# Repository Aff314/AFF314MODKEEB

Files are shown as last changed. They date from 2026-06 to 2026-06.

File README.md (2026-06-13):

# AFF314MODKEEB
AFF314MODKEEB is a 4x12 lowprofile keyboard. What makes it special are its modules. You can attach modules on top or on the right side which are connected with are then connected by magnets.

I had the idea because I daily drive 40% and 75% keyboards. I wanted to have one keyboard which can be used for both. With this keyboard you can have a full sized keyboard with number-keys, f-keys and arrow keys if you need it for a game or programm. But if you want to have a more minimal keyboard you can just detach the modules and have a nice and compact 40% keyboard. 

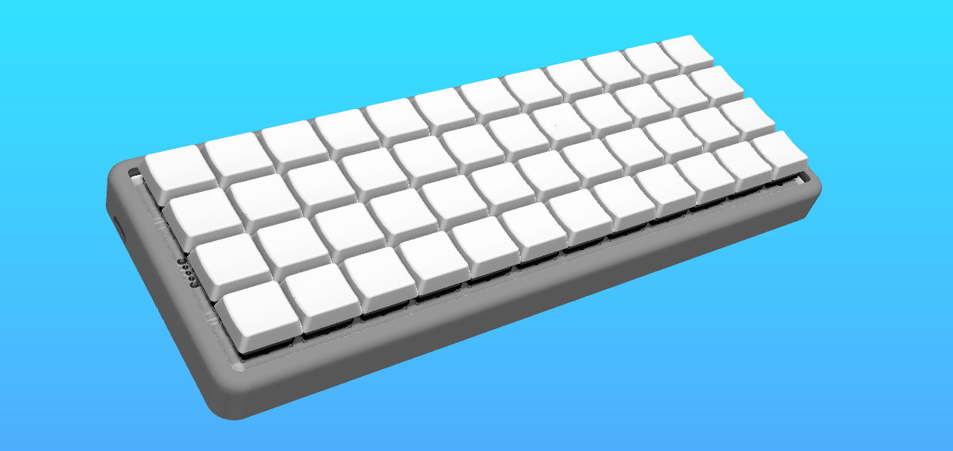
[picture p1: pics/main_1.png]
main_1


## Modules
You can attach the modules on top and on the right side.
So far I have designed three modules.

One for the right side. It has arrow-keys plus six extra keys that can be used for what ever you like.
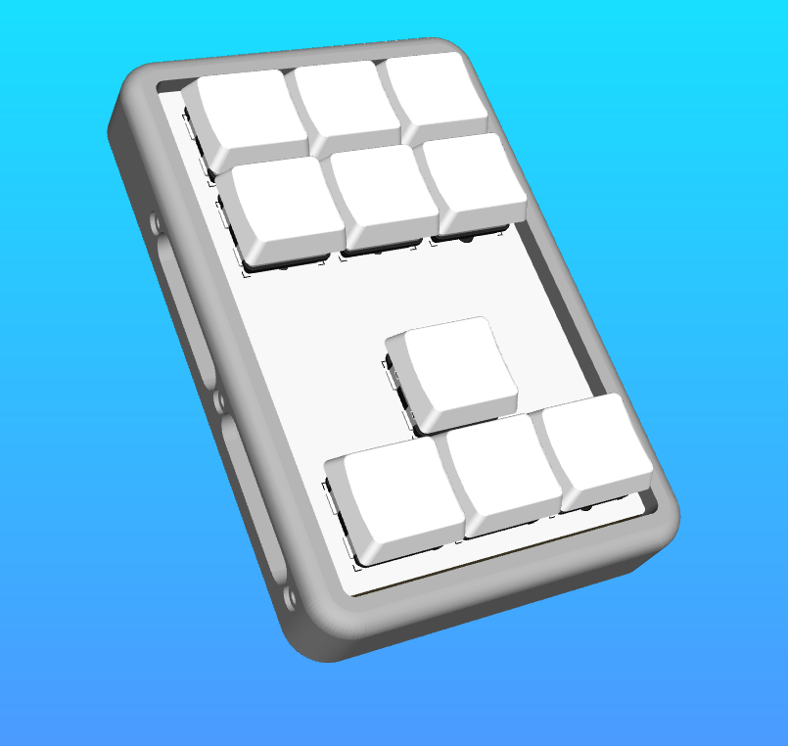
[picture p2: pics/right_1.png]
right_picture


The two that go on top are either a number or f-key row or a number plus f-key module. I decided to only order the pcbs for the number plus f-key module since you can type the numbers and f-keys also with layers so when I really need the f-keys or numbers the others don't hurt and it would take away from that convenience I wanted if you have so many modules laying around.
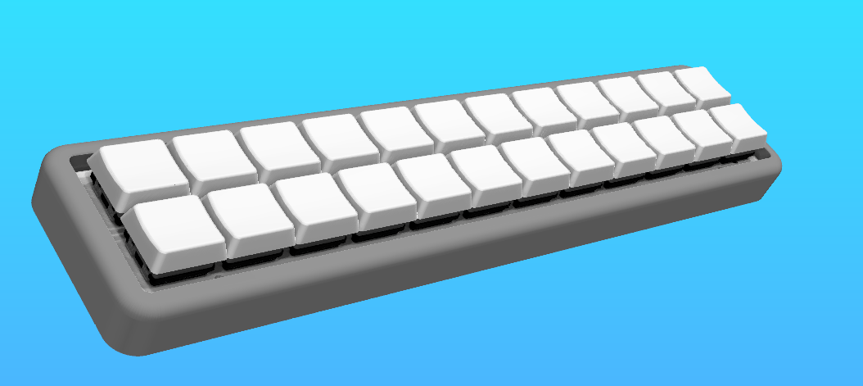
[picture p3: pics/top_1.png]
top_picture


If you want to you can design your own modules. You can use the same cases I designed and you have to modify the [pcbs](./pcb).

## Building
If you want to build the keyboard you have to not only solder on the pcb but also solder some wires. Once the keyboard is built I will add pictures for better understanding.

### Flashing
To flash the firmware you have to download the [UF2 file](./firmware/firmware.uf2).

### PCB
On the pcbs you first have to solder on all the diodes and hotswap sockets. Then you can solder on the power switch if you want to use one, because you can also use it without a powerswitch and solder the battery directly or just use it wired.

### Connectors
Before we wire everything we need the prepare the connectors. For this you need to print the [mounting bracktets](./3d). Then you can melt the heat inserts in the mounting bracket and attach it to the magnetic connector.

### Case
We also need to prepare the case. This is pretty straight forward as you only need to add the heat inserts.

### Wiring
We will start with the magnetic connectors we have prepared. We need to wire the cables to the pins. It is probably a good idea to use heat shrink tubing to isolate the exposed pins right by eachother but you dont have to. Once the wires are soldered to them we take them and mount them inside the case.
Look at the [schematics](./pics) and at the [wiring_guides](./pics) for help.

You can wire them to the mcu now. You also need to wire the rows and columns from the pcb to the mcu. For this you can take a look at the pcb but I will also add pictures once it's build.
At last you can wire the battery.

### MCU
The nice nano or if built wired the rp2040 will fit perfectly in the cutout for it in the bottom of the case. Optionaly you could glue it in place but it will also hold on its own so there is no need fo it unless you want the most secure fit.

## Fallout
I made this keyboard for fallout from hackclub and they give the chance for you to show off your project in a magazine. This is my page for zine. I will change it once I've built it irl because the real pictures would make it look way better.

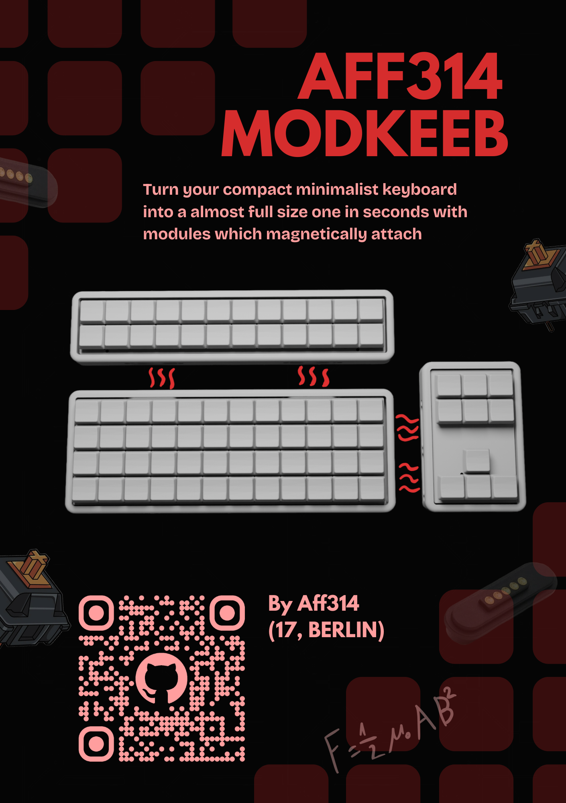
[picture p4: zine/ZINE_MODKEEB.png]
zine


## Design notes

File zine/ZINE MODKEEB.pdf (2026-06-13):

# AFF314 MODKEEB

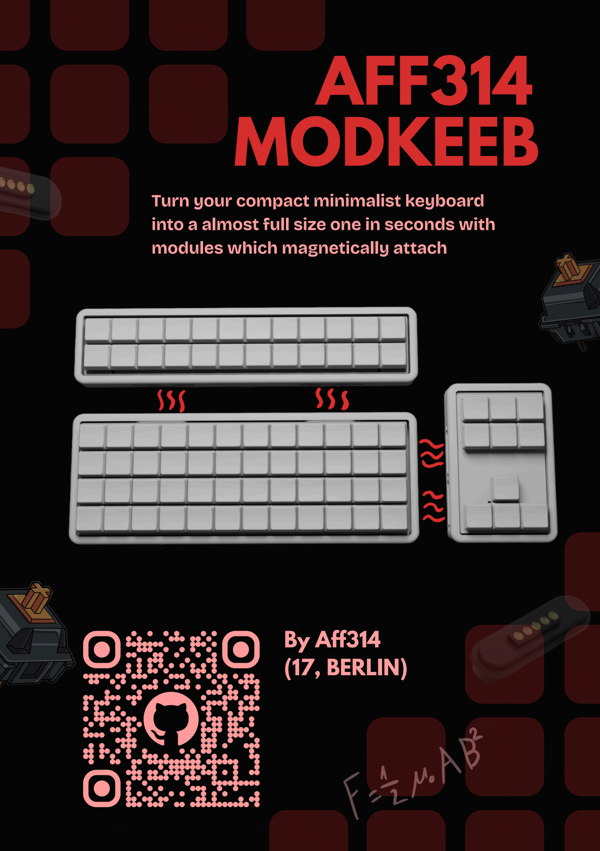
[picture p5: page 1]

### By Aff314 (17, BERLIN)

Turn your compact minimalist keyboard into a almost full size one in seconds with modules which magnetically attach

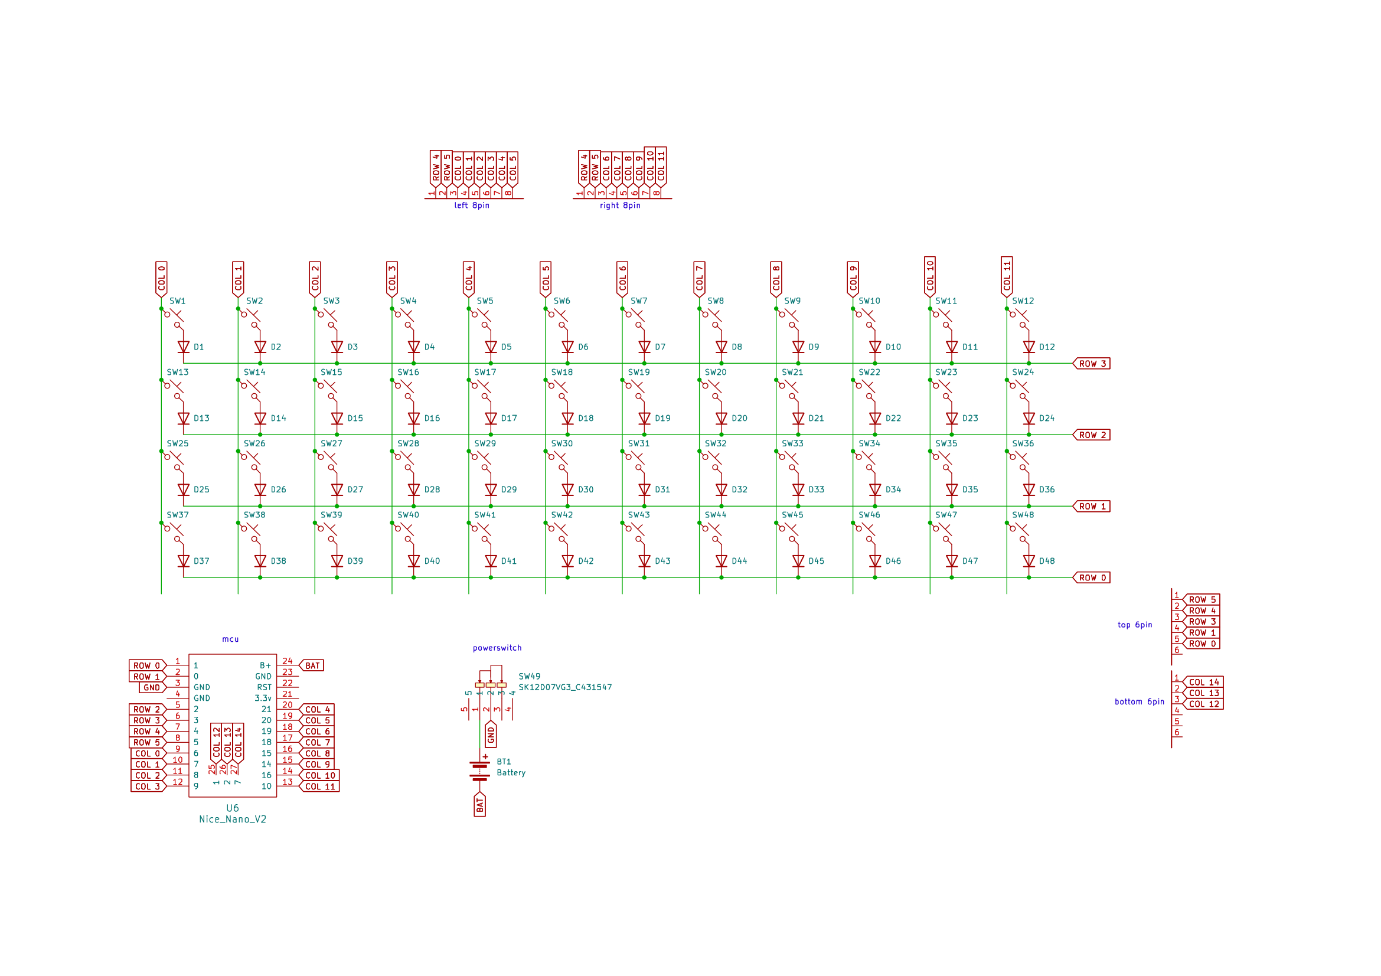
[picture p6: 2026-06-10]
pics/schematic.png

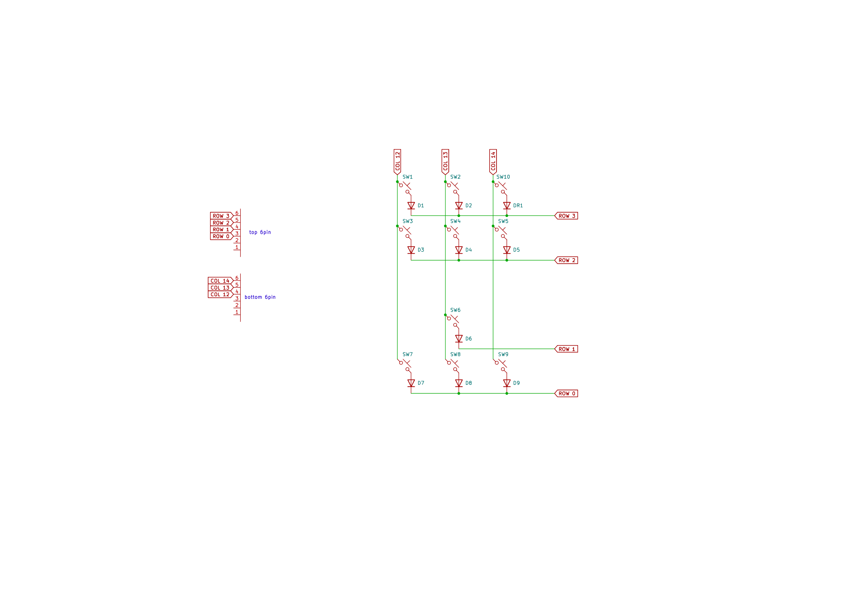
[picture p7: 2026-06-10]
pics/schematic_right.png

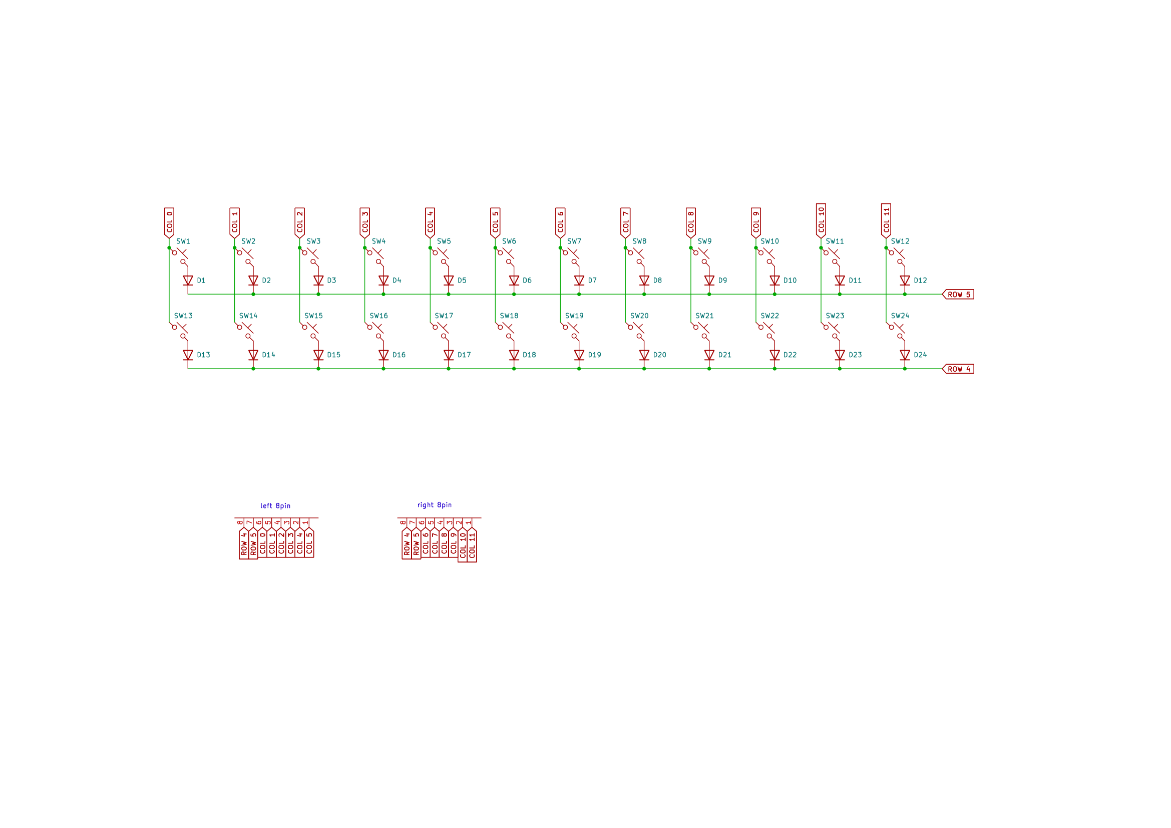
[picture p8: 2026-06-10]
pics/schematic_top.png

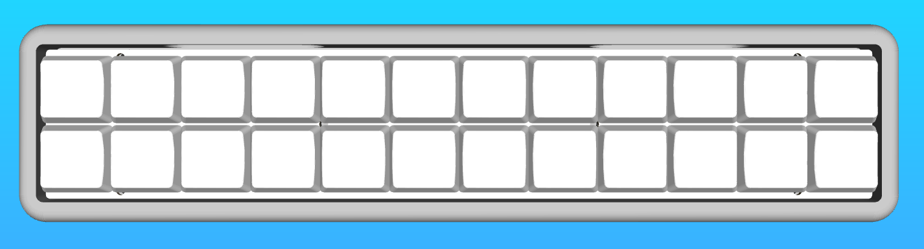
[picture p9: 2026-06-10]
pics/top_2.png

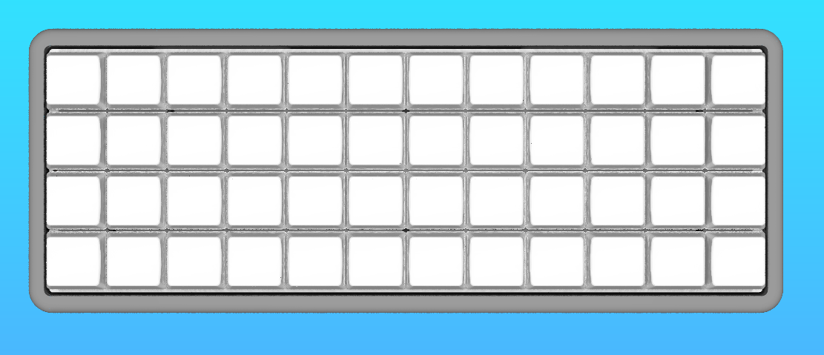
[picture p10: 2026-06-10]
pics/main_2.png

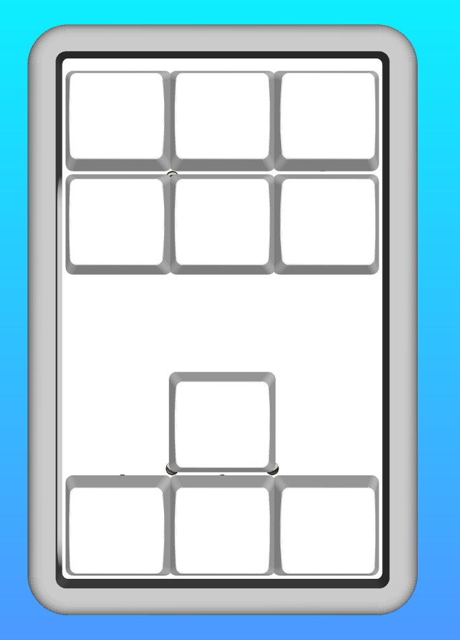
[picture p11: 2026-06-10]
pics/right_2.png

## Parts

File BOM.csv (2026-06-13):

name | qty | cost | link
keyswitch | 81 | 26€ | https://de.aliexpress.com/item/1005005723938995.html
keycap | 81 | 41€ | https://de.aliexpress.com/item/1005009231476056.html
hotswapsocket | 81 | 7.5€ | https://de.aliexpress.com/item/1005006105603269.html
magnetic connector 6pin | 2 | 8€ | https://de.aliexpress.com/item/1005007454862634.html
magnetic connector 8pin | 2 | 9€ | https://de.aliexpress.com/item/1005002669709542.html
1N4148W sod123 | 82 | 1.5€ | https://de.aliexpress.com/item/1005007160563285.html
ec11 | 1 | 2€ | https://de.aliexpress.com/item/1005005983134515.html
nrf52840 | 1 | 3.5€ | https://de.aliexpress.com/item/1005006403146060.html
SK12D07VG | 1 | 1€ | https://de.aliexpress.com/item/32882694396.html
battery | 1 | 8€ | https://ampul.eu/de/batterie/6269-li-pol-akku-600-mah-37-v-302580
m2 screws | 22 | 1.5€ | https://de.aliexpress.com/item/1005005070119421.html
heat insert m2 OD3.2mm | 22 | 2€ | https://de.aliexpress.com/item/1005004535859664.html
some wires (I used 28AWG) | ? | 3.5€ | https://de.aliexpress.com/item/1005004874605989.html
pcbs | 1 each | 30€ | https://github.com/Aff314/AFF314MODKEEB/tree/main/pcb
cases | 1 each | ? | https://github.com/Aff314/AFF314MODKEEB/tree/main/3d
total |  | ~100€

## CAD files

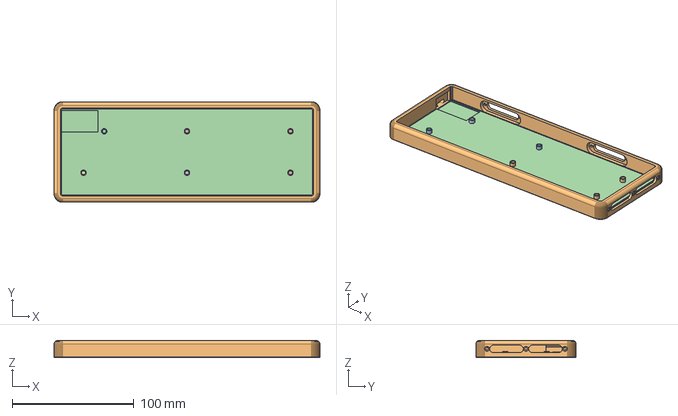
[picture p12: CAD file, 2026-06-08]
3d/step/main_case.stp
218.5 x 82.5 x 14.0 mm

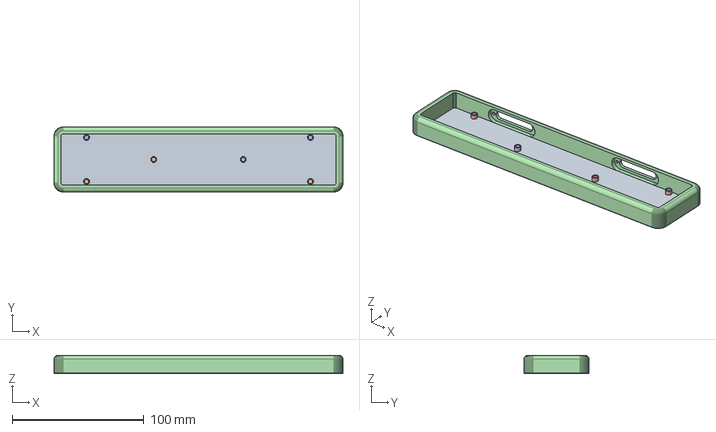
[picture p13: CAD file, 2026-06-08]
3d/step/module_top2_case.stp
219.5 x 49.5 x 14.0 mm

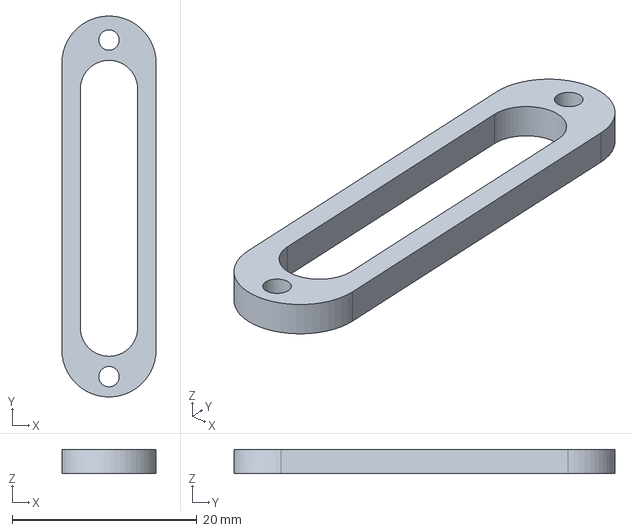
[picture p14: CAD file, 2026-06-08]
3d/step/magnetic_mounting_8pin_female.stp
10.2 x 41.2 x 2.60 mm

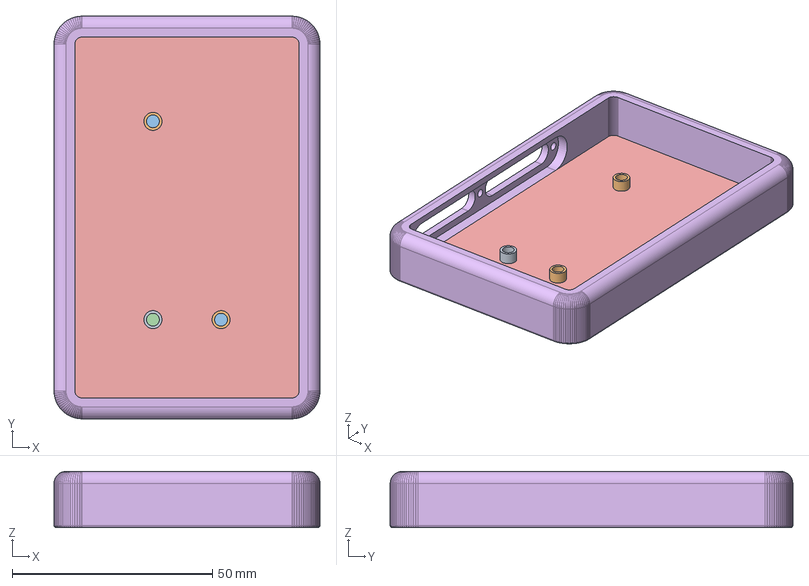
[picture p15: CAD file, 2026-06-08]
3d/step/module_right_case.stp
66.4 x 100.5 x 14.0 mm

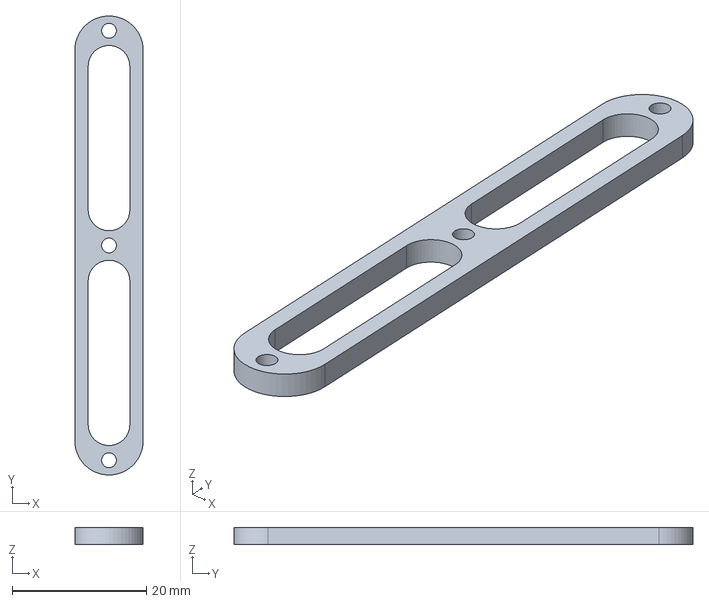
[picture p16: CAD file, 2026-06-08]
3d/step/magnetic_mounting_2x6pin_female.stp
10.2 x 68.4 x 2.60 mm

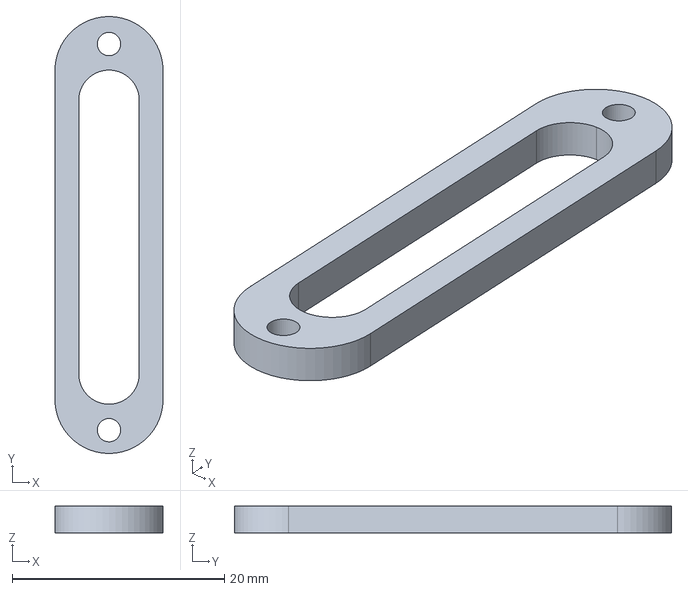
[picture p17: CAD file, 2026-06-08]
3d/step/magnetic_mounting_8pin_male.stp
10.2 x 41.2 x 2.50 mm

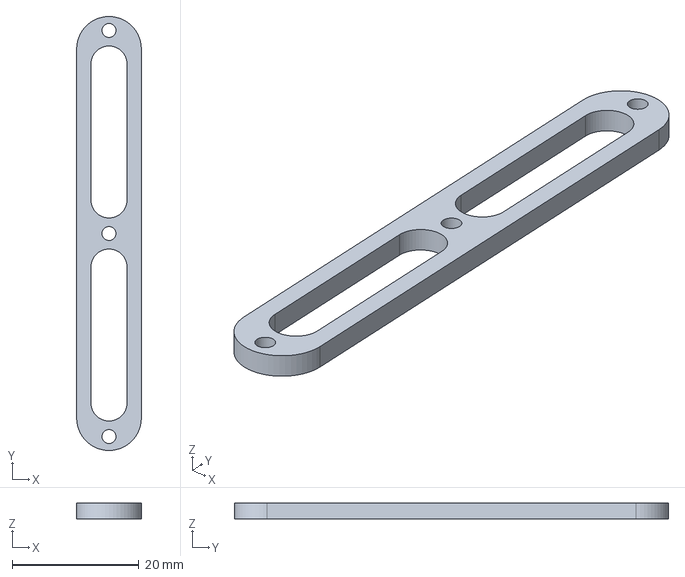
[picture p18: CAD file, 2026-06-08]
3d/step/magnetic_mounting_2x6pin_male.stp
10.2 x 68.4 x 2.50 mm

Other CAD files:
3d/stl/magnetic_mounting_2x6pin_female.stl
3d/stl/magnetic_mounting_2x6pin_male.stl
3d/stl/magnetic_mounting_8pin_female.stl
3d/stl/magnetic_mounting_8pin_male.stl
3d/stl/main_case.stl
3d/stl/module_right_case.stl
3d/stl/module_top2_case.stl

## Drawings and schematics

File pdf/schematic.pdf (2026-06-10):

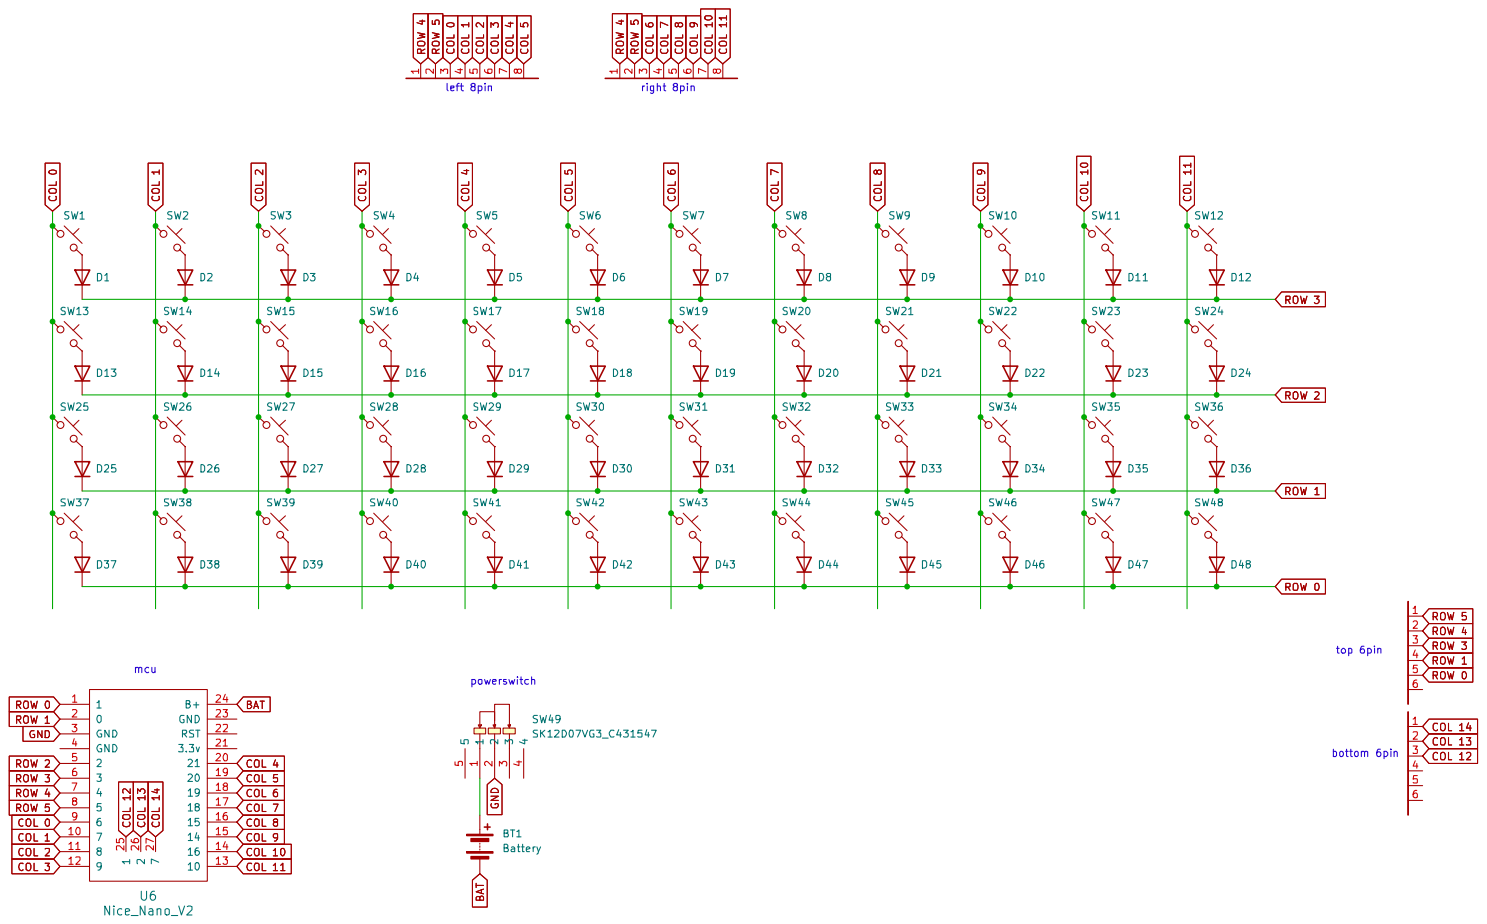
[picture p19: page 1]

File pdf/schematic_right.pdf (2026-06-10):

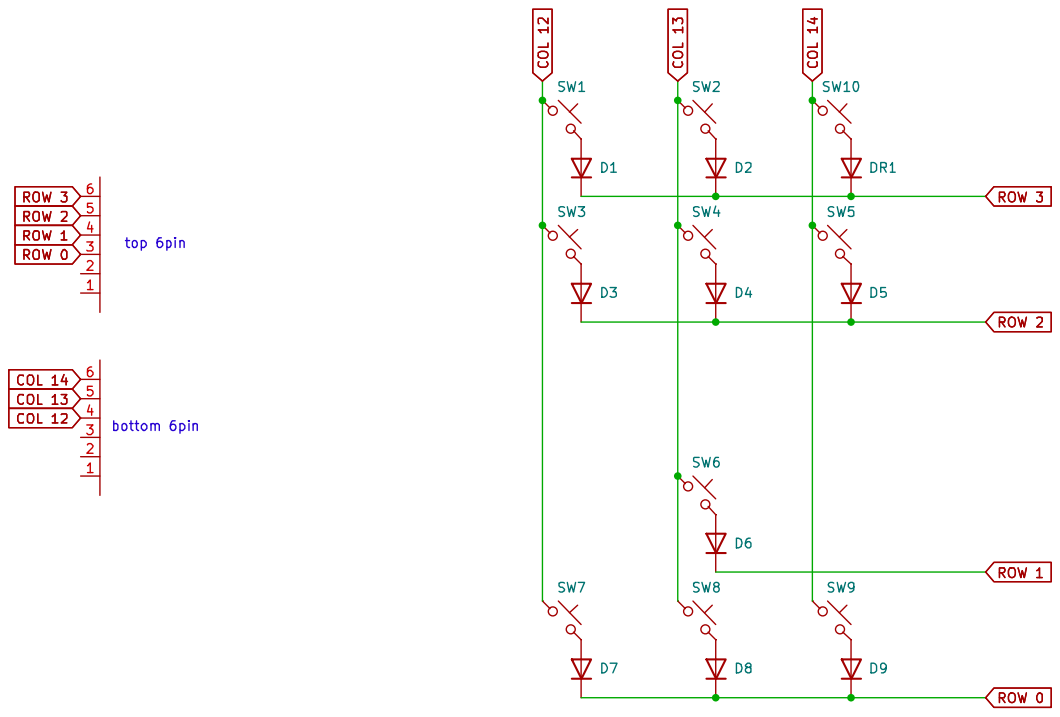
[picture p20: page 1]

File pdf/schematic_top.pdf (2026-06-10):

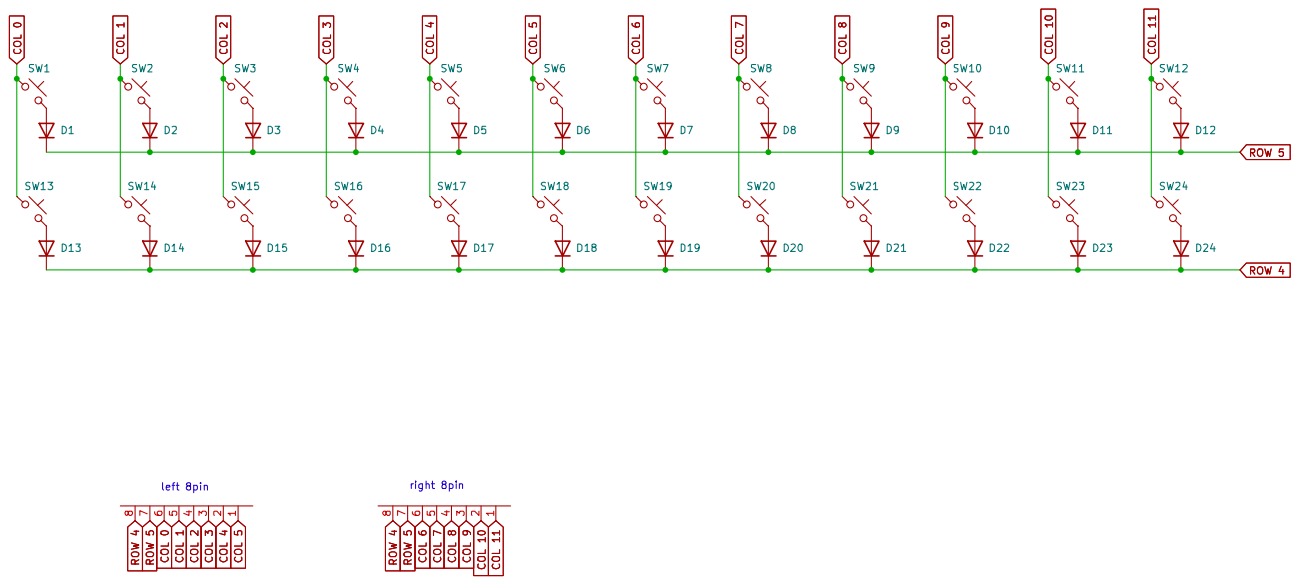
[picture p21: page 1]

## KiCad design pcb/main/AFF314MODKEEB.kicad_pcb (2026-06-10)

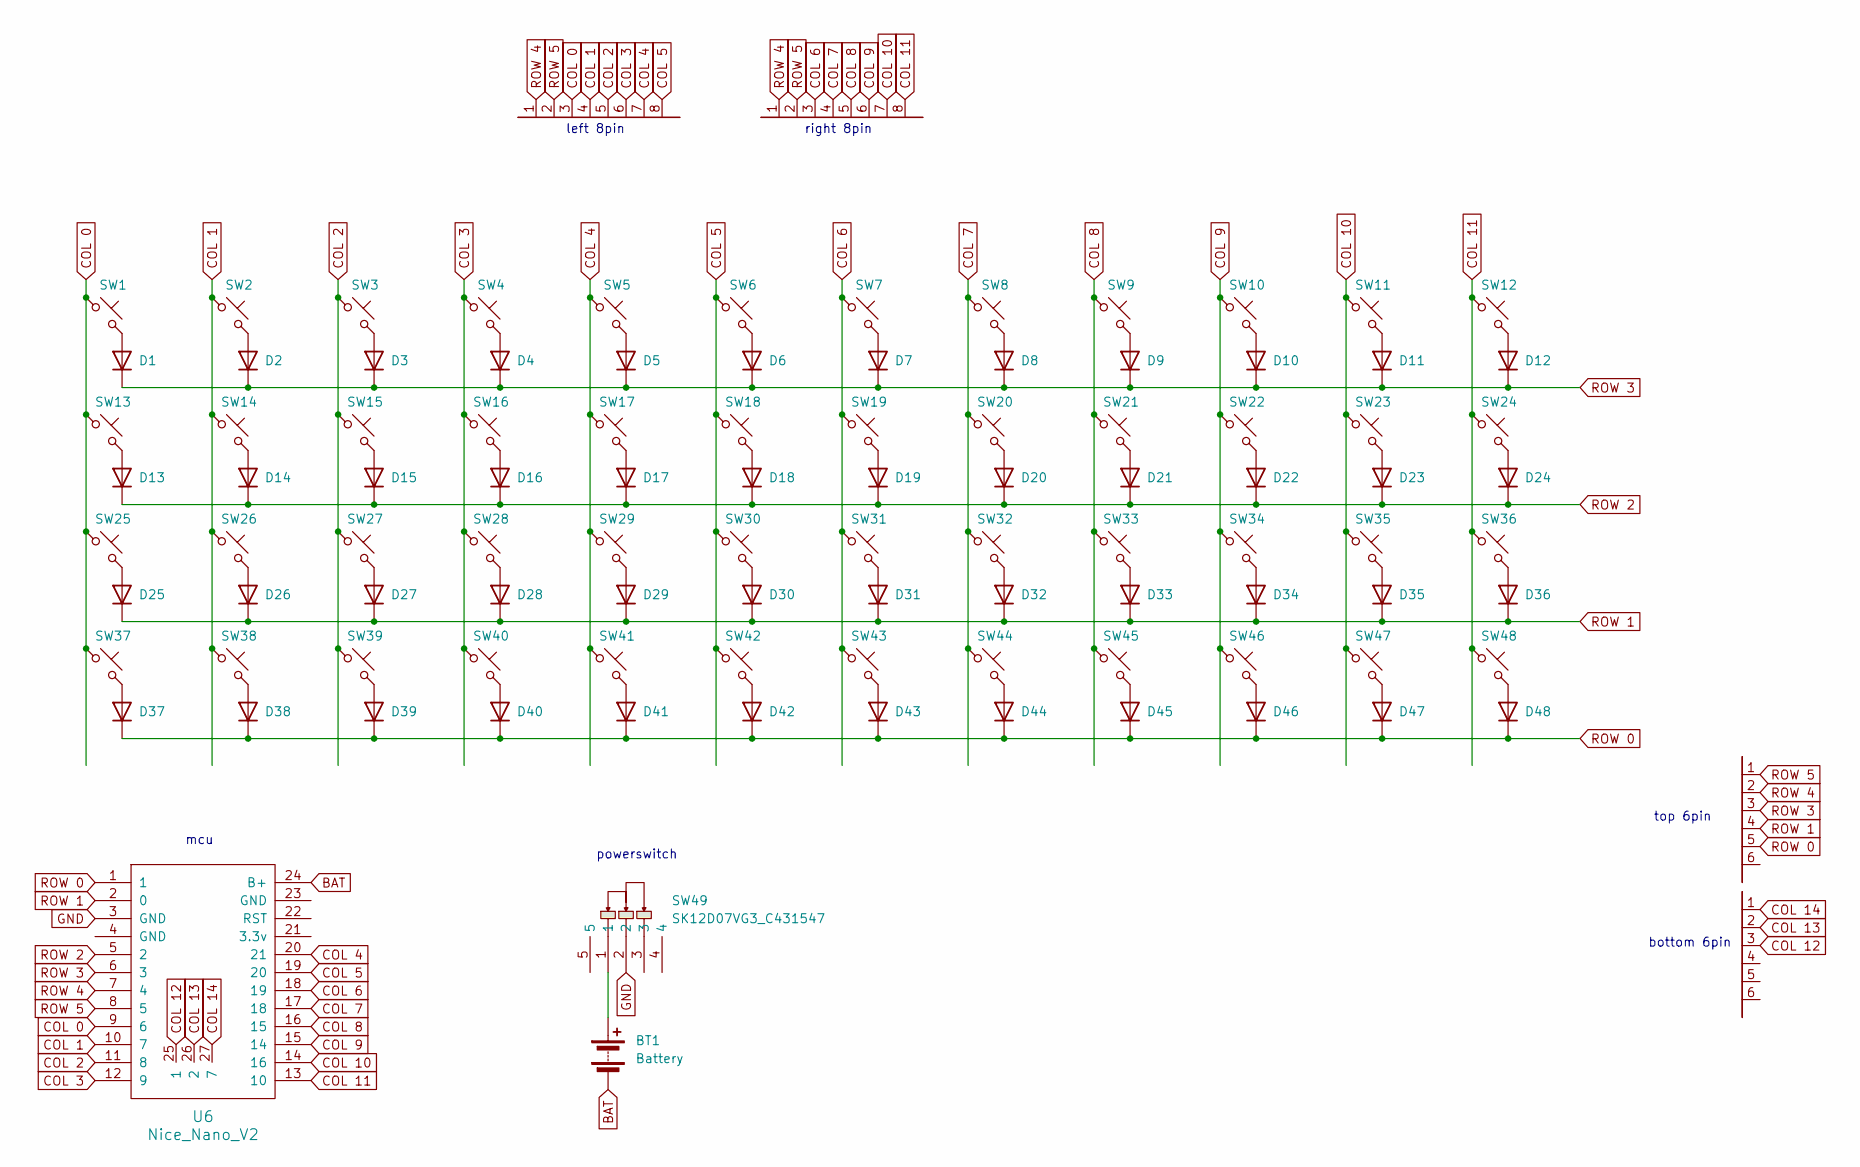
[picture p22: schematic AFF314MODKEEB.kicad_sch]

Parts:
BT1: Battery
D1, D2, D3, D4, D5, D6, D7, D8, D9, D10, D11, D12, D13, D14, D15, D16, D17, D18, D19, D20, D21, D22, D23, D24, D25, D26, D27, D28, D29, D30, D31, D32, D33, D34, D35, D36, D37, D38, D39, D40, D41, D42, D43, D44, D45, D46, D47, D48: D; Diode_SOD123
SW1, SW2, SW3, SW4, SW5, SW6, SW7, SW8, SW9, SW10, SW11, SW12, SW13, SW14, SW15, SW16, SW17, SW18, SW19, SW20, SW21, SW22, SW23, SW24, SW25, SW26, SW27, SW28, SW29, SW30, SW31, SW32, SW33, SW34, SW35, SW36, SW37, SW38, SW39, SW40, SW41, SW42, SW43, SW44, SW45, SW46, SW47, SW48: SW_Push_45deg; choc_16
SW49: SK12D07VG3_C431547; SW-TH_SK12D07VG3; MPN SK12D07VG3; LCSC Part C431547
U2, U3, U5, U7: (no value)
U6: Nice_Nano_V2

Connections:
COL 0: SW1.1, SW13.1, SW25.1, SW37.1, U5.3, U6.9 (6)
COL 1: SW2.1, SW14.1, SW26.1, SW38.1, U5.4, U6.10 (7)
COL 2: SW3.1, SW15.1, SW27.1, SW39.1, U5.5, U6.11 (8)
COL 3: SW4.1, SW16.1, SW28.1, SW40.1, U5.6, U6.12 (9)
COL 4: SW5.1, SW17.1, SW29.1, SW41.1, U5.7, U6.20 (21)
COL 5: SW6.1, SW18.1, SW30.1, SW42.1, U5.8, U6.19 (20)
COL 6: SW7.1, SW19.1, SW31.1, SW43.1, U6.18 (19), U7.3
COL 7: SW8.1, SW20.1, SW32.1, SW44.1, U6.17 (18), U7.4
COL 8: SW9.1, SW21.1, SW33.1, SW45.1, U6.16 (15), U7.5
COL 9: SW10.1, SW22.1, SW34.1, SW46.1, U6.15 (14), U7.6
COL 10: SW11.1, SW23.1, SW35.1, SW47.1, U6.14 (16), U7.7
COL 11: SW12.1, SW24.1, SW36.1, SW48.1, U6.13 (10), U7.8
unnamed: BT1.1 (+), SW49.1
unnamed: BT1.2 (-), U6.24 (B+)
unnamed: D1.2 (A), SW1.2
unnamed: D2.2 (A), SW2.2
unnamed: D3.2 (A), SW3.2
unnamed: D4.2 (A), SW4.2
unnamed: D5.2 (A), SW5.2
unnamed: D6.2 (A), SW6.2
unnamed: D7.2 (A), SW7.2
unnamed: D8.2 (A), SW8.2
unnamed: D9.2 (A), SW9.2
unnamed: D10.2 (A), SW10.2
unnamed: D11.2 (A), SW11.2
unnamed: D12.2 (A), SW12.2
unnamed: D13.2 (A), SW13.2
unnamed: D14.2 (A), SW14.2
unnamed: D15.2 (A), SW15.2
unnamed: D16.2 (A), SW16.2
unnamed: D17.2 (A), SW17.2
unnamed: D18.2 (A), SW18.2
unnamed: D19.2 (A), SW19.2
unnamed: D20.2 (A), SW20.2
unnamed: D21.2 (A), SW21.2
unnamed: D22.2 (A), SW22.2
unnamed: D23.2 (A), SW23.2
unnamed: D24.2 (A), SW24.2
unnamed: D25.2 (A), SW25.2
unnamed: D26.2 (A), SW26.2
unnamed: D27.2 (A), SW27.2
unnamed: D28.2 (A), SW28.2
unnamed: D29.2 (A), SW29.2
unnamed: D30.2 (A), SW30.2
unnamed: D31.2 (A), SW31.2
unnamed: D32.2 (A), SW32.2
unnamed: D33.2 (A), SW33.2
unnamed: D34.2 (A), SW34.2
unnamed: D35.2 (A), SW35.2
unnamed: D36.2 (A), SW36.2
unnamed: D37.2 (A), SW37.2
unnamed: D38.2 (A), SW38.2
unnamed: D39.2 (A), SW39.2
unnamed: D40.2 (A), SW40.2
unnamed: D41.2 (A), SW41.2
unnamed: D42.2 (A), SW42.2
unnamed: D43.2 (A), SW43.2
unnamed: D44.2 (A), SW44.2
unnamed: D45.2 (A), SW45.2
unnamed: D46.2 (A), SW46.2
unnamed: D47.2 (A), SW47.2
unnamed: D48.2 (A), SW48.2
unnamed: U2.1, U5.2, U6.8 (5), U7.2
unnamed: U2.2, U5.1, U6.7 (4), U7.1
unnamed: U3.1, U6.27 (7)
unnamed: U3.2, U6.26 (2)
unnamed: U3.3, U6.25 (1)
unnamed: SW49.2, U6.3 (GND)
ROW 0: D37.1 (K), D38.1 (K), D39.1 (K), D40.1 (K), D41.1 (K), D42.1 (K), D43.1 (K), D44.1 (K), D45.1 (K), D46.1 (K), D47.1 (K), D48.1 (K), U2.5, U6.1
ROW 1: D25.1 (K), D26.1 (K), D27.1 (K), D28.1 (K), D29.1 (K), D30.1 (K), D31.1 (K), D32.1 (K), D33.1 (K), D34.1 (K), D35.1 (K), D36.1 (K), U2.4, U6.2 (0)
ROW 2: D13.1 (K), D14.1 (K), D15.1 (K), D16.1 (K), D17.1 (K), D18.1 (K), D19.1 (K), D20.1 (K), D21.1 (K), D22.1 (K), D23.1 (K), D24.1 (K), U6.5 (2)
ROW 3: D1.1 (K), D2.1 (K), D3.1 (K), D4.1 (K), D5.1 (K), D6.1 (K), D7.1 (K), D8.1 (K), D9.1 (K), D10.1 (K), D11.1 (K), D12.1 (K), U2.3, U6.6 (3)

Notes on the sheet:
right 8pin
powerswitch
top 6pin
bottom 6pin
left 8pin
mcu

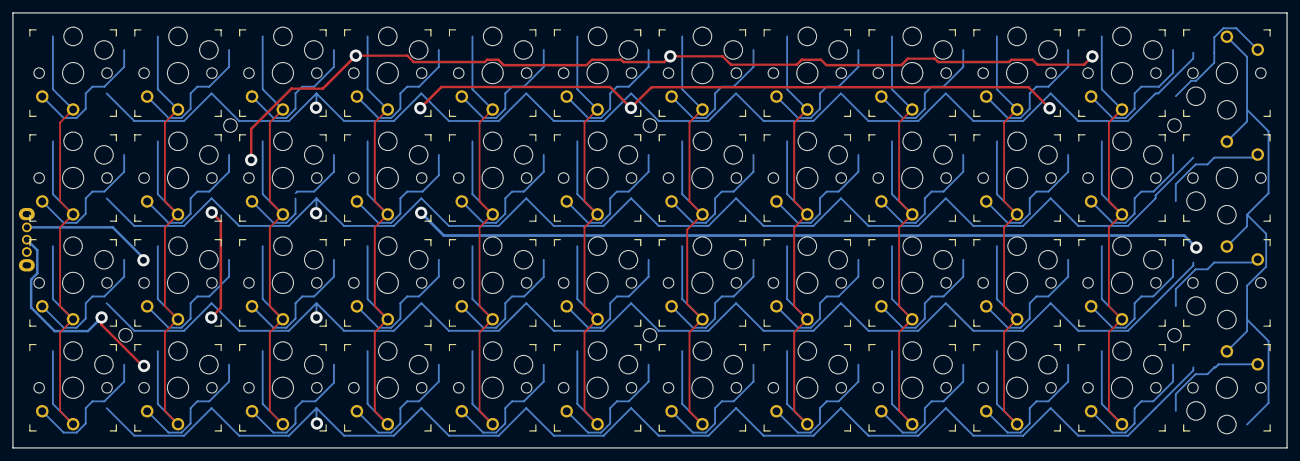
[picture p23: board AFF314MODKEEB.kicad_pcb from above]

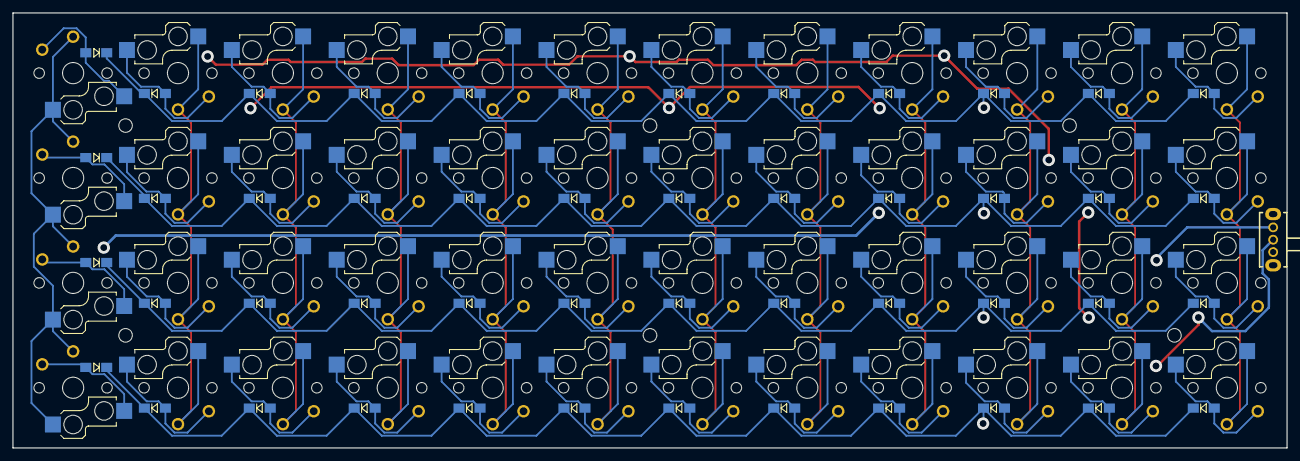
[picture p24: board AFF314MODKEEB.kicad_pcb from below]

Board: 2 copper layers, 206.5 x 70.5 mm, 97 parts (49 on the bottom side), 64 nets.

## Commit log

2026-06-08 add pcb and 3d
    [AFF314MODKEEB.kicad_pcb, AFF314MODKEEB.kicad_sch, magnetic_mounting_2x6pin_female.stl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]
2026-06-08 Add BOM CSV file for keyswitch components
    [bom.csv]
2026-06-10 Add parts to BOM
    [bom.csv]
2026-06-10 update pcb & add firmware
    [AFF314MODKEEB.kicad_pcb, AFF314MODKEEB.kicad_sch, bom.csv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]
2026-06-10 Add wire details and update BOM entries
    [bom.csv]
2026-06-10 Update wiring instructions in README
    Added references to schematics and wiring guides for clarity.
2026-06-13 Format BOM.csv for consistency and clarity
    [BOM.csv, bom.csv]
